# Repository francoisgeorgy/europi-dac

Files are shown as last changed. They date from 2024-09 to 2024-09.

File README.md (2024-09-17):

# A 4 channels DAC for the EuroPi

This is a custom PCB that add a four channels DAC to the [EuroPi](https://allensynthesis.co.uk/modules/europi.html).

The DAC is a [MCP4728](https://www.microchip.com/en-us/product/mcp4728) : 

* 12-Bit Resolution
* 4 Buffered Voltage Outputs
* Single-Supply Operation: 2.7V to 5.5V
* On-Board Non-Volatile Memory (EEPROM)
* Normal or Power-Down Mode
* Internal or External Voltage Reference Selection
* Rail-to-Rail Output
* Low Power Consumption
* ±0.2 LSB DNL (typical)
* Address bits: User Programmable toEEPROM
* Standard (100 kbps), Fast (400 kbps) and High Speed (3.4 Mbps) Modes

The voltage reference is a [LM4040](https://www.analog.com/en/products/lm4040.html), 3.0V. 

The DAC outputs are connected to the EuroPi 3, 4, 5 and 6 outputs as follows : 

| EuroPi output | DAC channel |
|---:|---:|
| 1 | |
| 2 | |
| 3 | D |
| 4 | B |
| 5 | C |
| 6 | A |

This specific order of the channels was chosen to facilitate the PCB routing. 

The EuroPi outputs 1 and 2 do not change and are still driven with a PWM output from the Pico.

#### Power supply : 

This custom PCB swaps the 10-pin Eurorack power connector for a 16-pin one and removes the onboard power regulator, 
opting to use the 5V directly from the Eurorack power supply instead.

## Schematic

Here is the schematic of this PCB : [dac-board-v2.1.pdf](hardware%2Fdac-board-v2.1%2Fplot%2Fdac-board-v2.1.pdf)

## Why build this custom PCB?

This PCB project was mainly a fun excuse to experiment and learn:

- [KiCad](https://www.kicad.org/) practice: a good opportunity to get better at PCB design.
- SMD assembly with [JLCPCB](https://jlcpcb.com/): tried out having the board made and assembled by an external provider.
- Eurorack power filtering: played around with filtering power right on the PCB.
- DAC vs PWM outputs: wanted to see if DAC outputs really outperform PWM for basic CV voltages.
- Just for fun: because DIY projects are always more fun!

## License

This custom PCB is licensed under the same terms and conditions as the original EuroPi. 

This module, and any documentation included in this repository, is entirely "free" software and hardware, 
under different licenses depending on the software, hardware, and documentation itself.

* Software: [Apache 2.0](software/LICENSE)
* Hardware: [CERN OHL-S v2](hardware/LICENSE)
* Documentation: [CC0 1.0](LICENSE)

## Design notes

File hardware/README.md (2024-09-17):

## PCB versions

### [dac-board](dac-board) 

Do not use this version. The J2 and J3 connectors (headers that link the front panel) are incorrectly oriented.

### [dac-board-v2](dac-board-v2) 

This version is OK and has been successfully used with a regular EuroPi front-panel. 

### [dac-board-v2.1](dac-board-v2.1) 

This minor release fixes the connectors placement in KiCad. This version has not been tested yet.

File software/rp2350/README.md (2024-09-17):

How to use the new Pi Pico 2 with EuroPi 
========================================

Pimoroni offers a Pico 2 board that is a drop-in replacement for the Pico :

[Pimoroni Pico Plus 2](https://shop.pimoroni.com/products/pimoroni-pico-plus-2?variant=42092668289107)

### To use this board : 

1. Download and install the Pimoroni firmware from https://github.com/pimoroni/pimoroni-pico-rp2350

Select the **pico_plus2_rp2350** MicroPython Flavour. 
The current release (september 16th) is [pico_plus2_rp2350-v0.0.7-pimoroni-micropython.uf2](https://github.com/pimoroni/pimoroni-pico-rp2350/releases/download/v0.0.7/pico_plus2_rp2350-v0.0.7-pimoroni-micropython.uf2). 

2. Install the ssd1306 package.
3. Install the EuroPi software from the source files. 
You must not install the `micropython-europi` package nor use a `europi-vX.Y.Z.uf2` file.
4. Adapt the EuroPi scripts to work with the Pico 2.

### Software changes for the Pico 2 : 

The only change that really needs to be made is related to the ADC. We need to use the ADC channel number instead
of the Pin number.

In `europi.py`, in the `__init__` method of the `AnalogReader` class, replace : 

    self.pin = ADC(Pin(pin))

with : 

    self.pin = ADC(pin)

In `europi.py`, in the main code (end of the file), replace : 

    ain = AnalogueInput(PIN_AIN)
    k1 = Knob(PIN_K1)
    k2 = Knob(PIN_K2)

with :

    ain = AnalogueInput(0)
    k1 = Knob(1)          
    k2 = Knob(2)

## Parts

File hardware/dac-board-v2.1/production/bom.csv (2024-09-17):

Designator | Footprint | Quantity | Value | LCSC Part #
C1 | 0805 | 1 | 10uF | C15850
C10, C3, C4, C5, C6, C7, C8, C9 | 0402 | 8 | 100nF
C20, C21, C22, C23, C24, C25 | 1206 | 6 | 22uF | C12891
D1 | D_SOD-323 | 1 | 1N5817WS | C727114
D2, D3, D4, D5 | D_SMA | 4 | STPS1L30 | C157388
FB1, FB2, FB3 | 0805 | 3 | FerriteBead | C216152
J2, J3 | PinSocket_2x04_P2.54mm_Vertical | 2 | Conn_02x04_Odd_Even
Q1 | SOT-23 | 1 | MBT2222A | C8512
R1, R2 | 0402 | 2 | 1K
R21, R22, R23 | 0402 | 3 | 22K
R24, R25, R26 | 0402 | 3 | 10K
R27, R28, R29, R30, R31, R32, R33, R34 | 0402 | 8 | 100K
R35, R36, R37, R38, R39, R40 | 0402 | 6 | 220K
TP1, TP2, TP3, TP4, TP5, TP6 | TestPoint_Pad_D1.5mm | 6 | TestPoint
U1 | SOT-23 | 1 | LM4040B30FTA | C460604
U2 | MSOP-10_3x3mm_P0.5mm | 1 | MCP4728 | C108207
U3, U4 | SOIC-14_3.9x8.7mm_P1.27mm | 2 | TL074 | C107644
U5 | SOIC-8_3.9x4.9mm_P1.27mm | 1 | MCP6002 | C7377

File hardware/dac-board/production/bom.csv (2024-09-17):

Designator | Footprint | Quantity | Value | LCSC Part #
C1 | 0805 | 1 | 10uF | C15850
C10, C11, C12, C13, C14, C3, C4, C5, C6, C7, C8, C9 | 0402 | 12 | 100nF
C2 | 0402 | 1 | 1uF | C52923
C20, C21, C22, C23, C24, C25 | 1206 | 6 | 22uF | C12891
D1 | D_SOD-323 | 1 | 1N5817WS | C727114
D2, D3, D4, D5 | D_SMA | 4 | STPS1L30 | C157388
FB1, FB2, FB3 | 0805 | 3 | FerriteBead | C216152
J5 | PinHeader_1x02_P2.54mm_Horizontal | 1 | Conn_01x02_Pin
Q1 | SOT-23 | 1 | MBT2222A | C8512
R1, R2, R3, R4, R5, R6 | 0402 | 6 | 1K
R21, R22, R23 | 0402 | 3 | 22K
R24, R25, R26 | 0402 | 3 | 10K
R27, R28, R29, R30, R31, R32, R33, R34 | 0402 | 8 | 100K
R35, R36, R37, R38, R39, R40 | 0402 | 6 | 220K
U1 | SOT-23 | 1 | LM4040LP-3 | C143326
U2 | MSOP-10_3x3mm_P0.5mm | 1 | MCP4728 | C108207
U3, U4 | SOIC-14_3.9x8.7mm_P1.27mm | 2 | TL074 | C107644
U5 | SOIC-8_3.9x4.9mm_P1.27mm | 1 | MCP6002 | C7377

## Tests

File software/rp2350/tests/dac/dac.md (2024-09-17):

Custom board with MCP4728 DAC
=============================

| Front-board jack | Pico PWM / DAC output |
|---|---|
| Output 1 | PWM1 |
| Output 2 | PWM2 |
| Output 3 | DAC D ch 3 |
| Output 4 | DAC B ch 1 |
| Output 5 | DAC C ch 2 |
| Output 6 | DAC A ch 0 |

Firmware 
--------

New classes : 

    OutputPWM
    OutputDAC

Changed class : 

    Output is parent of OutputPWM and OutputDAC

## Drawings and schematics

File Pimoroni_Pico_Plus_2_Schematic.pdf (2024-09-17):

## MCU2 RP2350B

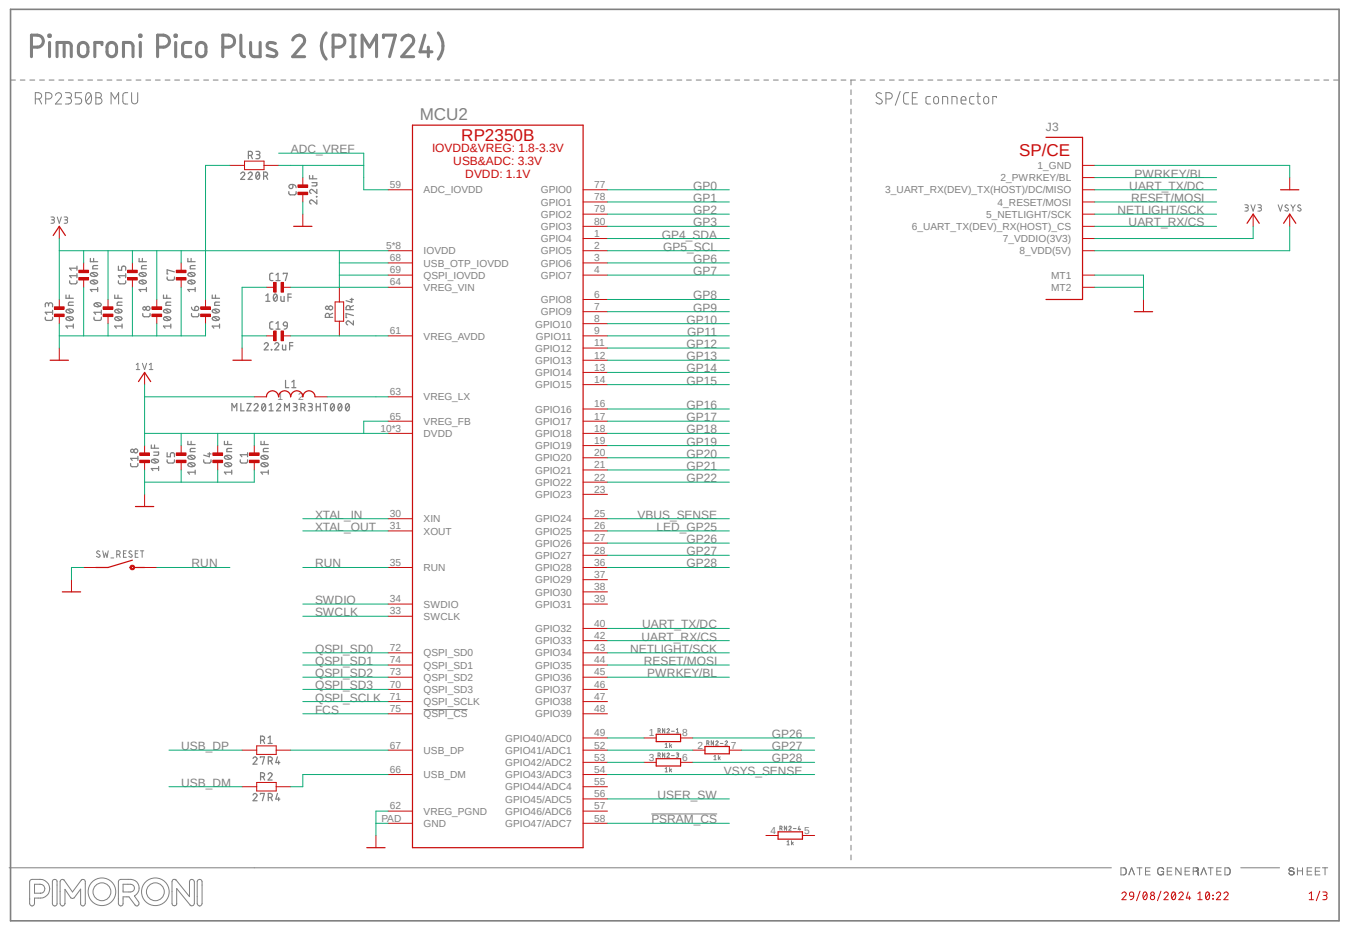
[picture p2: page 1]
IOVDD 5*8; GND PAD; QSPI_SD0 72 QSPI_SD1 74 QSPI_SD2 73 QSPI_SD3 70 QSPI_SCLK 71 QSPI_CS 75; VREG_AVDD 61; VREG_PGND 62; USB_DP 67; USB_DM 66; SWCLK 33; SWDIO 34; RUN 35; XOUT 31; ADC_IOVDD 59; GPIO0; GPIO1; GPIO2; GPIO3; GPIO4; GPIO5; GPIO6; GPIO7; GPIO8; GPIO9; GPIO10; GPIO11; GPIO12; GPIO13; GPIO14; GPIO15; GPIO16; GPIO17; GPIO18; GPIO19; GPIO20; GPIO21; GPIO22; GPIO23; GPIO24; GPIO25; VREG_FB 65; VREG_LX 63; GPIO26; GPIO27; GPIO28; GPIO29; GPIO30; GPIO31; GPIO32; GPIO33; GPIO34; GPIO35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

3_UART_RX(DEV)_TX(HOST)/DC/MISO

USB_OTP_IOVDD 68 | GP6
QSPI_IOVDD 69 | GP7
VREG_VIN 64 | GP8

DVDD 10*3 | GP18

XTAL_IN | XIN 30 | GP19

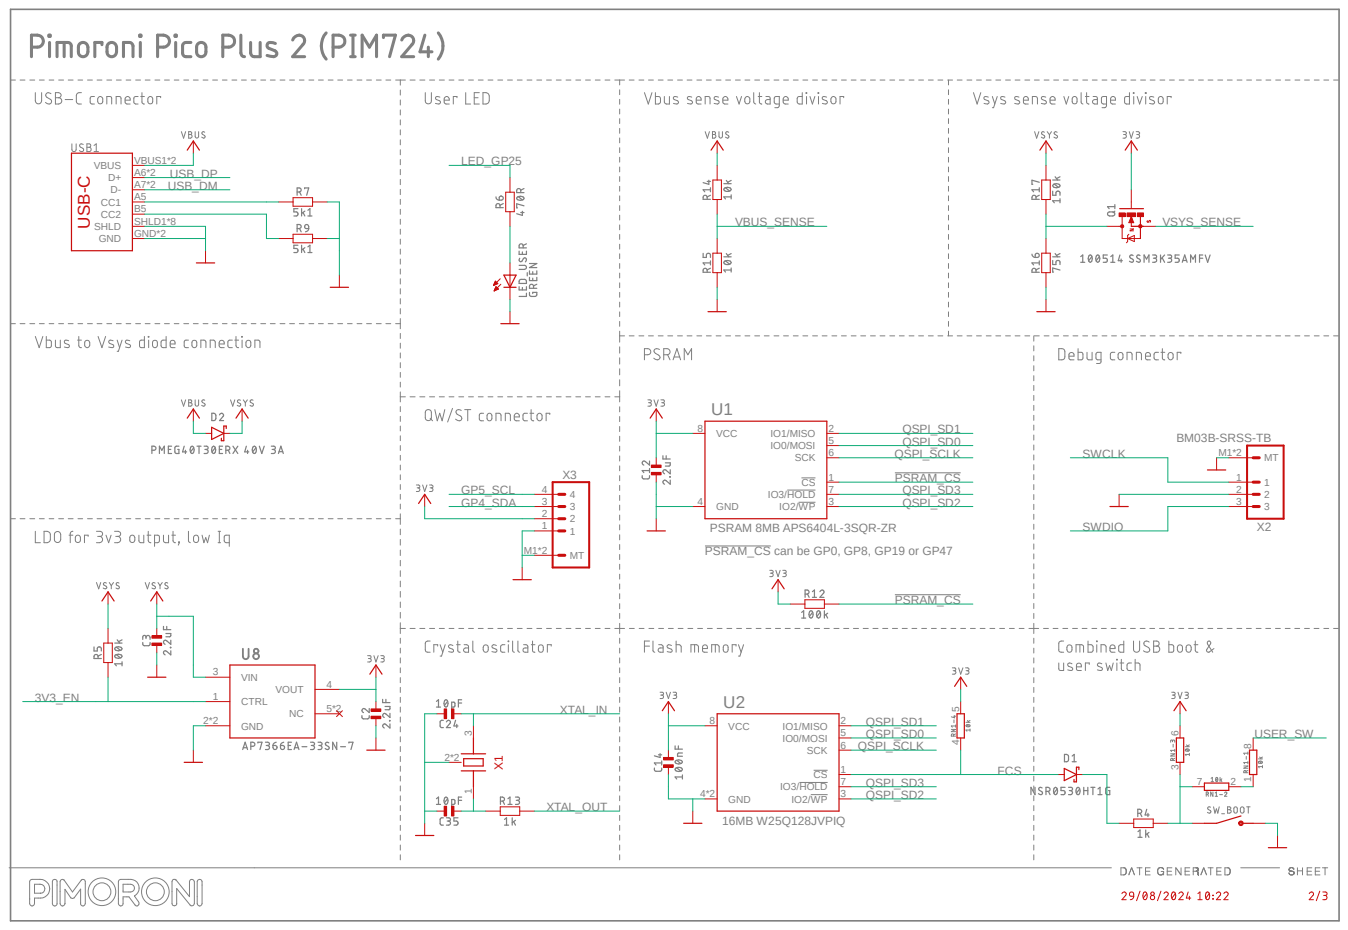
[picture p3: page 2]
16MB W25Q128JVPIQ; BM03B-SRSS-TB; GND; GND*2; VBUS; VBUS1*2; SHLD; SHLD1*8; 2 ³ ⁶ ⁴ ⁵ VCC 8; IO1/MISO; IO0/MOSI; GND 4*2; SCK; IO3/HOLD; VCC 8; VIN 3; GND 2*2; CTRL 1; VOUT; USB_DP USB_DM; QSPI_SD1; QSPI_SD2; QSPI_SD3; QSPI_SCLK; FCS; XTAL_IN; XTAL_OUT; QSPI_SD0; USER_SW; GP5_SCL; LED_GP25; GP4_SDA; PSRAM_CS; VBUS_SENSE; VSYS_SENSE; SWCLK; SWDIO; 3V3_EN USB⁻C

GND 4
PSRAM 8MB APS6404L-3SQR-ZR
PSRAM_CS can be GP0, GP8, GP19 or GP47

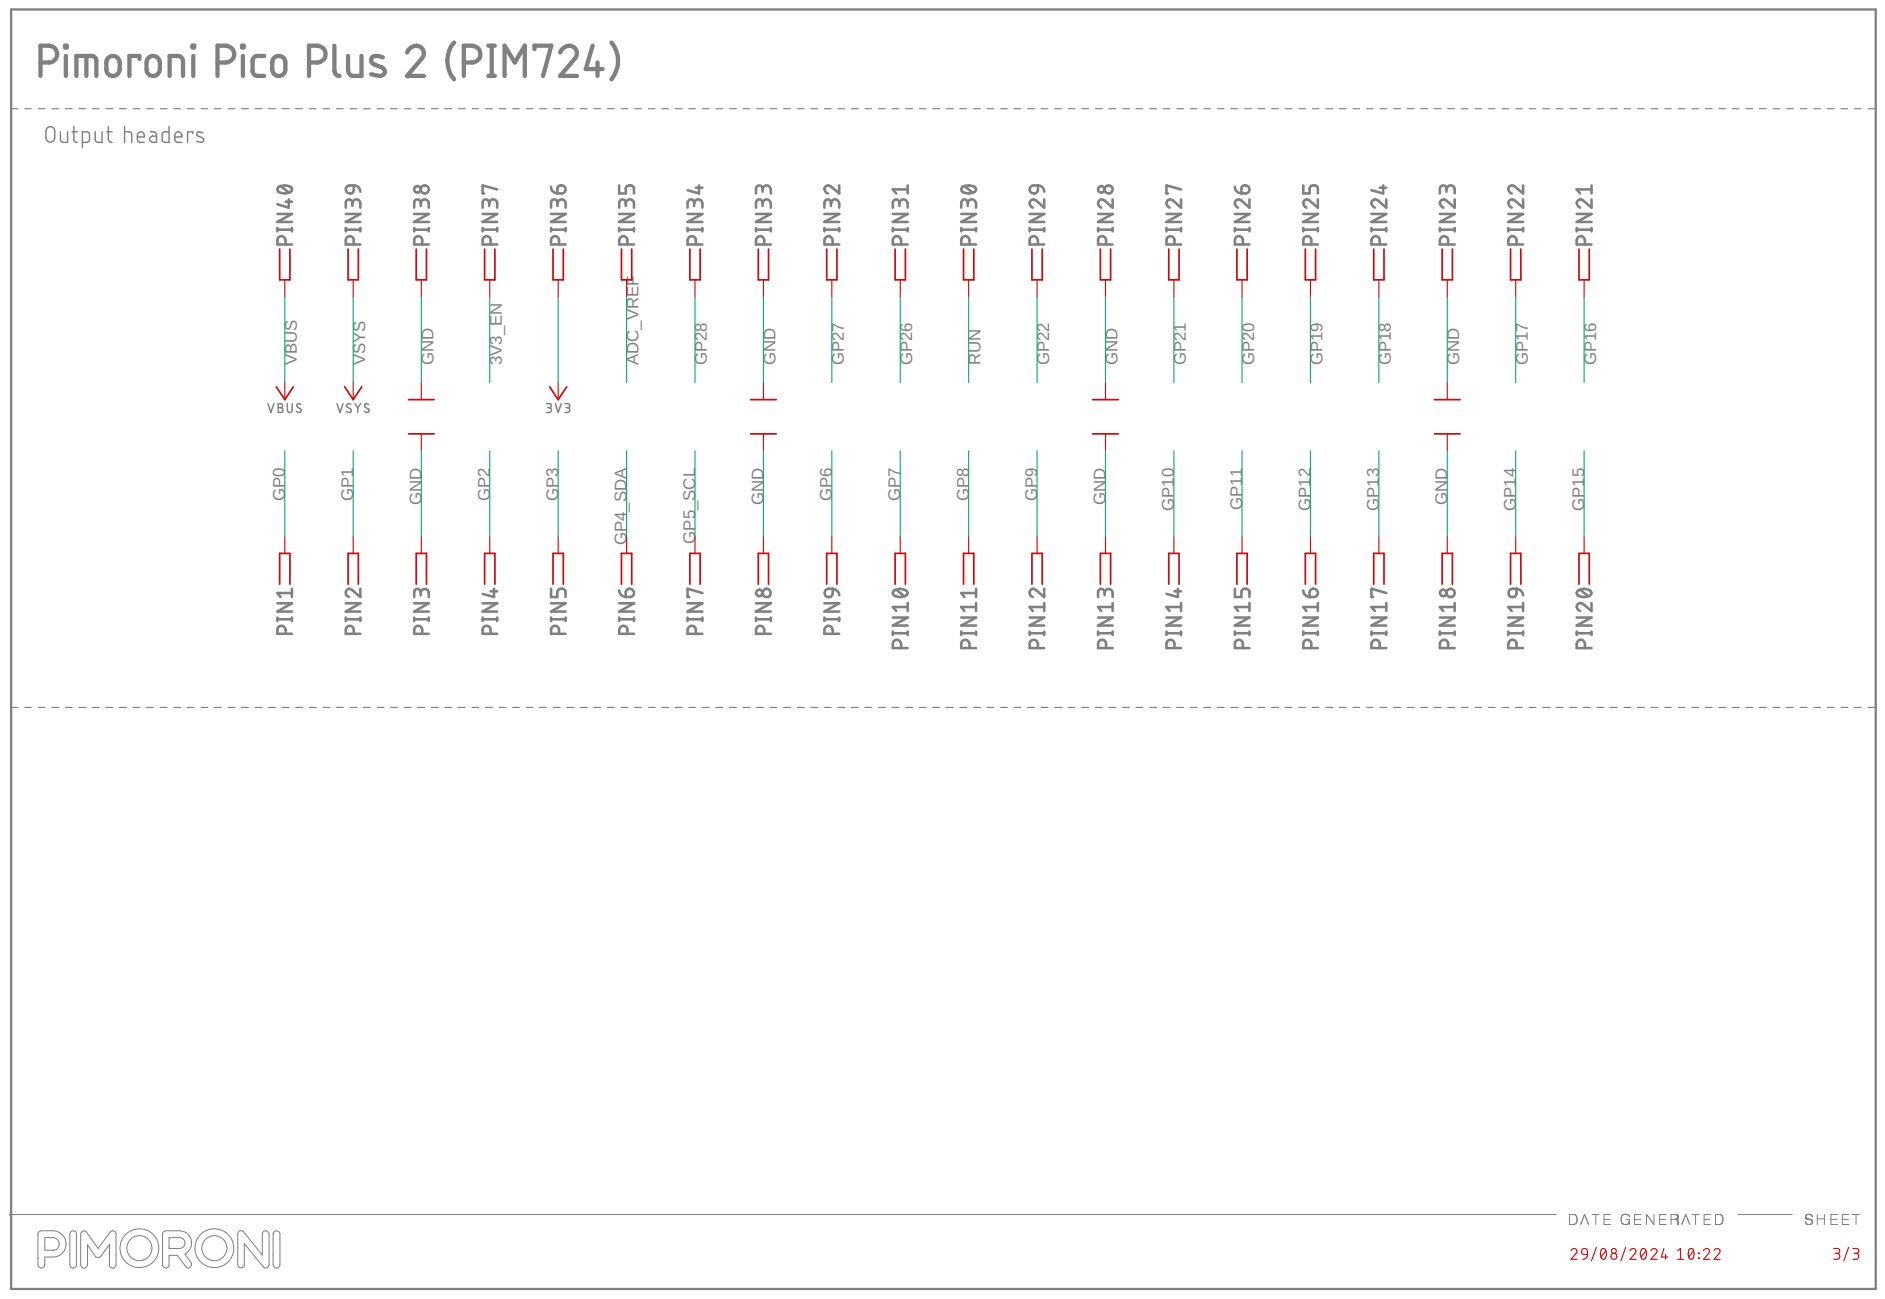
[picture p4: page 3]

GND GND GND GND GND GND GND GND GP0 GP1 GP2 GP3 GP4_SDA GP5_SCL GP6 GP7 GP8 GP9 GP10 GP11 GP12 GP13 GP14 GP15 VBUS VSYS 3V3_EN ADC_VREF GP28 GP27 GP26 RUN GP22 GP21 GP20 GP19 GP18 GP17 GP16

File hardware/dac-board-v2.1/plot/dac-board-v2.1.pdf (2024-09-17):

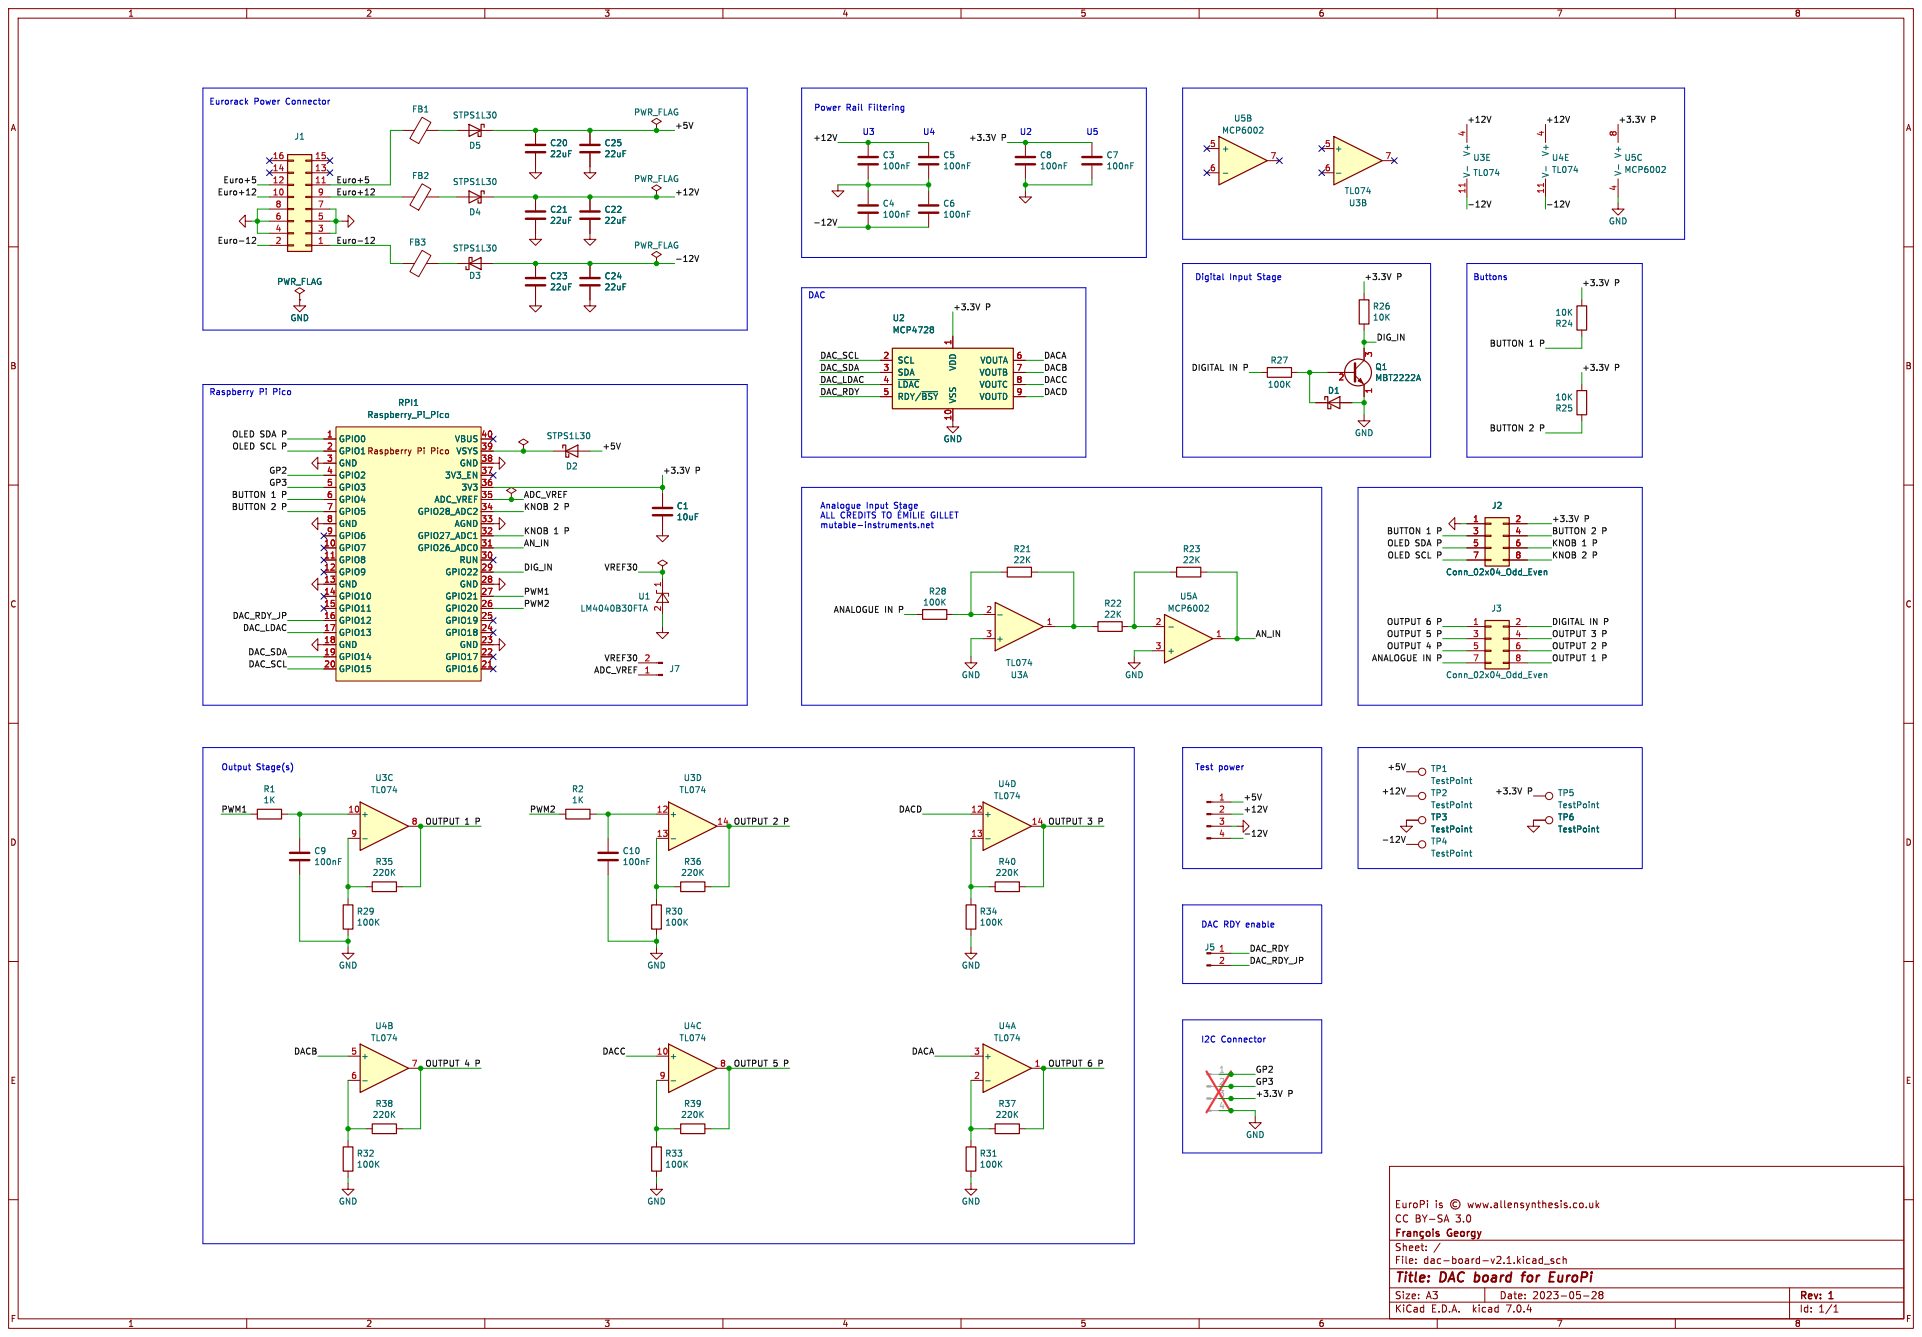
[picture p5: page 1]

1 VSS 10 SCL 2 SDA 3 ~{LDAC} 4 RDY/~{BSY} 5 VOUTA 6 VOUTB 7 VOUTC 8 VOUTD 9 U2 MCP4728 FB2 PWR_FLAG

Power Rail Filtering DAC

1 VSS 10 SCL 2 SDA 3 ~{LDAC} 4 RDY/~{BSY} 5 VOUTA 6 VOUTB 7 VOUTC 8 VOUTD 9 GND GND

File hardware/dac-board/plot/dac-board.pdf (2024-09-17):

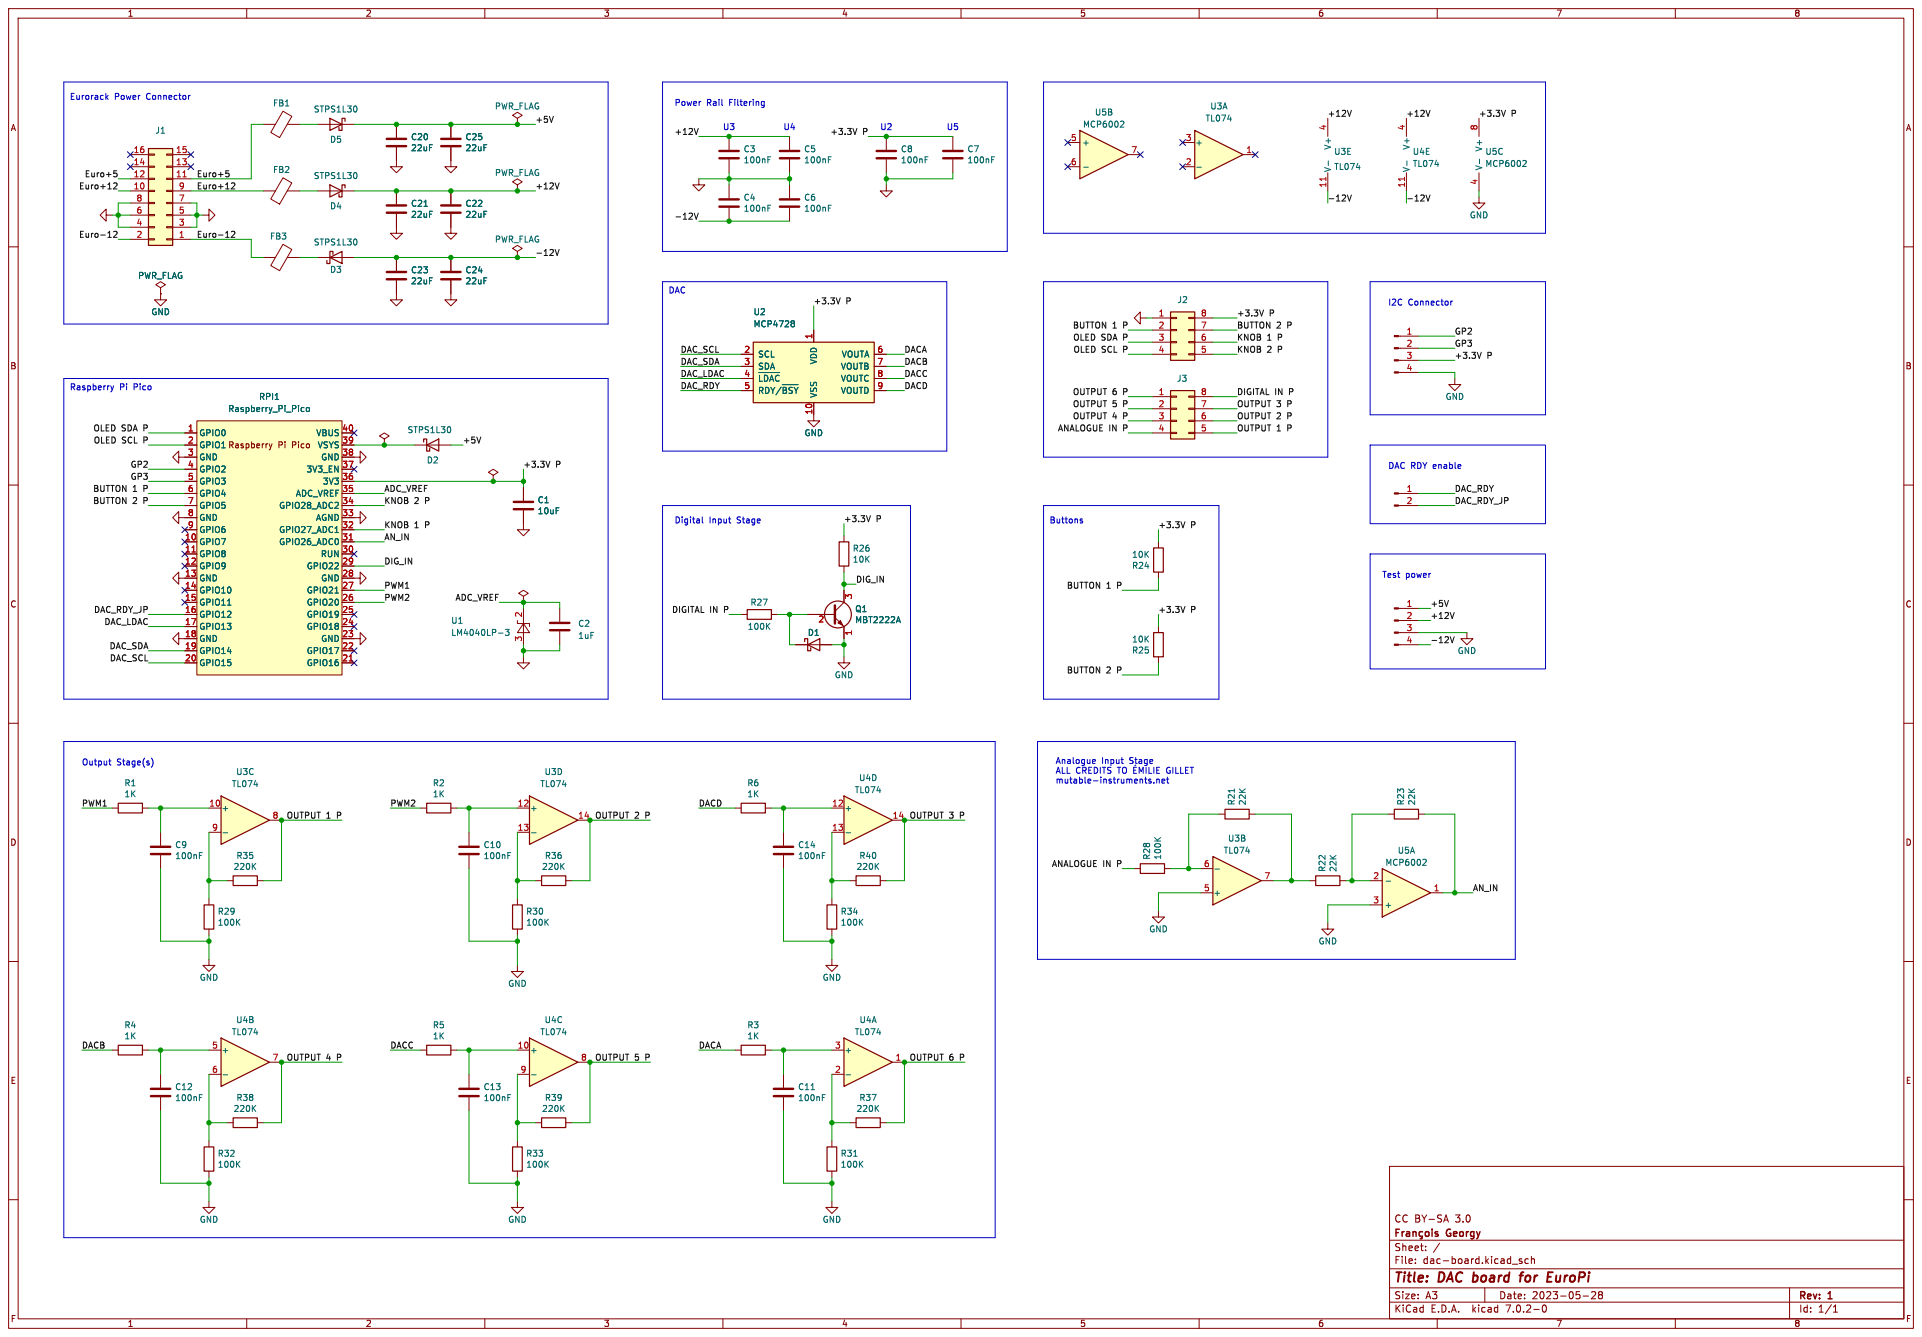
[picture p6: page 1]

U3 Power Rail Filtering Eurorack Power Connector

1 VSS 10 SCL 2 SDA 3 ~{LDAC} 4 RDY/~{BSY} 5 VOUTA 6 VOUTB 7 VOUTC 8 VOUTD 9 U2 MCP4728 +
ADC_VREF PWM2 KNOB 2 P

BUTTON 1 P OUTPUT 5 P OLED SCL P OLED SDA P

BUTTON 2 P
KNOB 1 P
KNOB 2 P DIGITAL IN P OUTPUT 3 P

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

DAC RDY enable Digital Input Stage

Analogue Input Stage ALL CREDITS TO þÿÉMILIE GLLET mutable-instruments.net

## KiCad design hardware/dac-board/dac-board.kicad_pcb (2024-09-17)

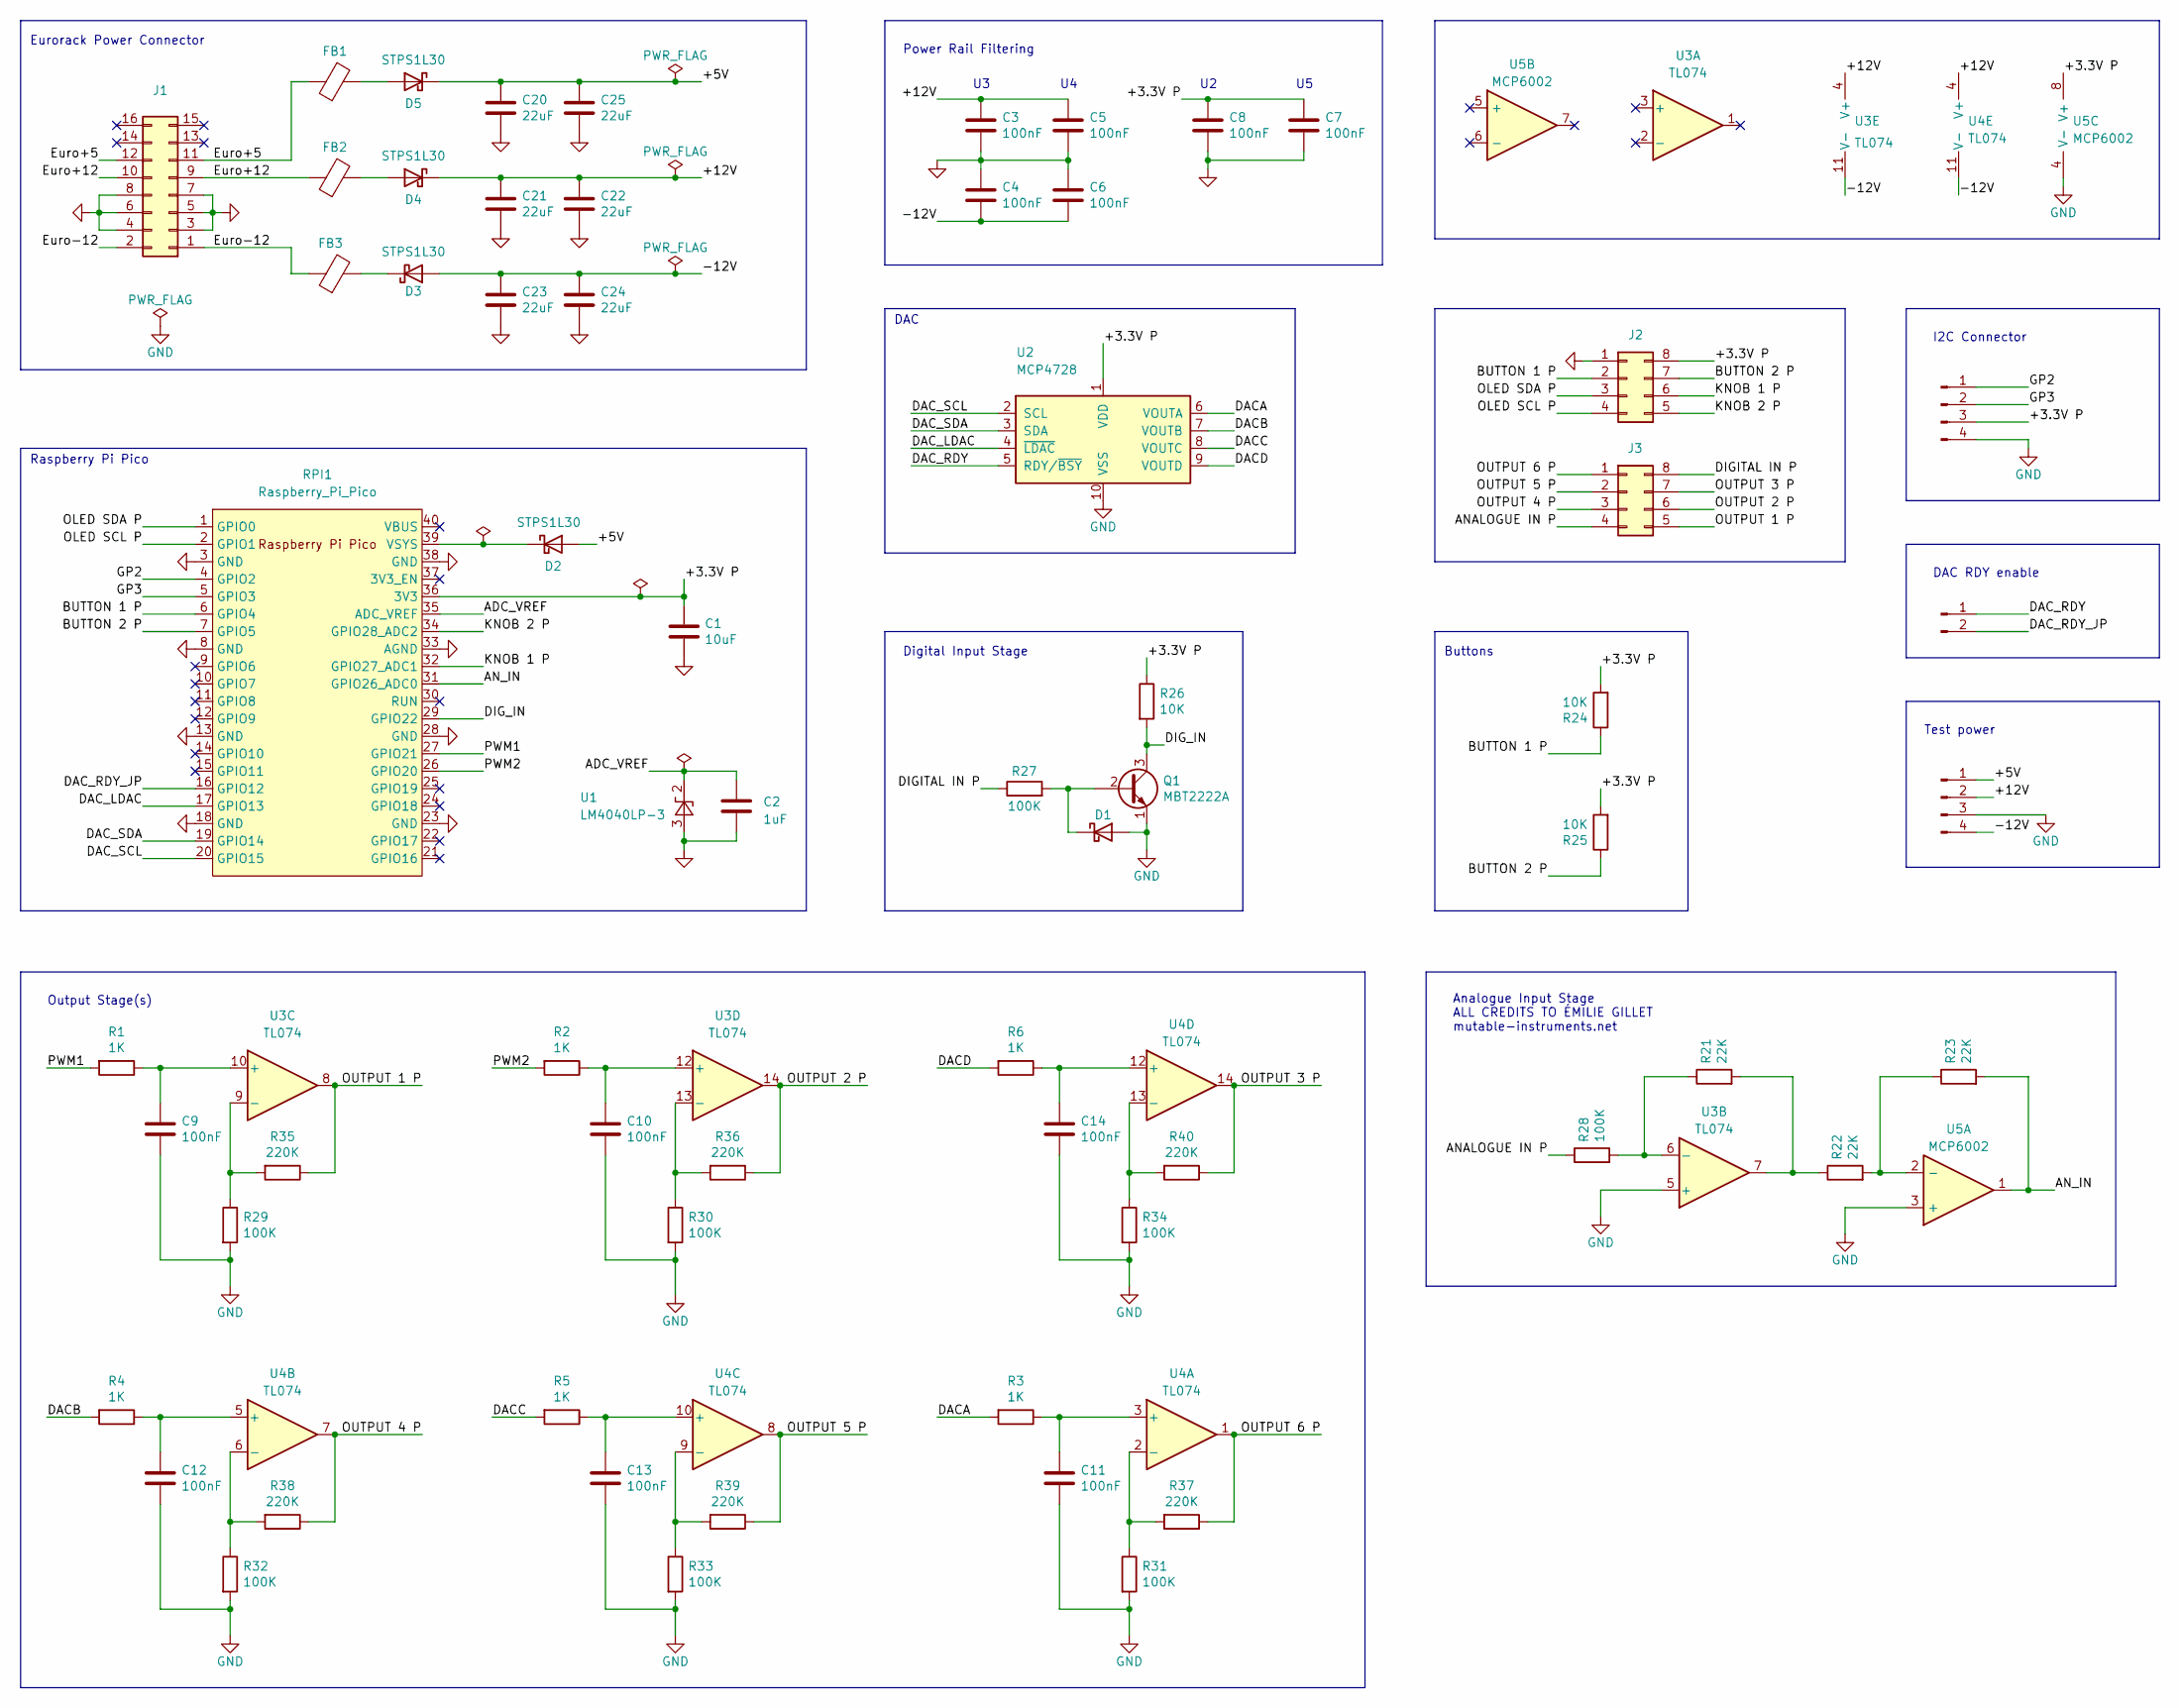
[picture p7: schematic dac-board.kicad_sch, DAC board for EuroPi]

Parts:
C1: 10uF; C_0805_2012Metric; JLCPCB Part # C15850
C2: 1uF; C_0402_1005Metric; JLCPCB Part # C52923
C3, C4, C5, C6, C7, C8, C9, C10, C11, C12, C13, C14: 100nF; C_0402_1005Metric
C20, C21, C22, C23, C24, C25: 22uF; C_1206_3216Metric; JLCPCB Part # C12891
D1: 1N5817WS; D_SOD-323; JLCPCB Part # C727114
D2, D3, D4, D5: STPS1L30; D_SMA; JLCPCB Part # C157388
FB1, FB2, FB3: FerriteBead; L_0805_2012Metric; JLCPCB Part # C216152
J1: Conn_02x08_Odd_Even; IDC-Header_2x08_P2.54mm_Vertical
J2, J3: Conn_02x04_Counter_Clockwise; PinHeader_2x04_P2.54mm_Vertical
J4, J6: Conn_01x04_Male; PinHeader_1x04_P2.54mm_Vertical
J5: Conn_01x02_Pin; PinHeader_1x02_P2.54mm_Horizontal
Q1: MBT2222A; SOT-23; JLCPCB Part # C8512
R1, R2, R3, R4, R5, R6: 1K; R_0402_1005Metric
R21, R22, R23: 22K; R_0402_1005Metric
R24, R25, R26: 10K; R_0402_1005Metric
R27, R28, R29, R30, R31, R32, R33, R34: 100K; R_0402_1005Metric
R35, R36, R37, R38, R39, R40: 220K; R_0402_1005Metric
RPI1: Raspberry_Pi_Pico; Raspberry Pi Pico
U1: LM4040LP-3; SOT-23; JLCPCB Part # C143326
U2: MCP4728; MSOP-10_3x3mm_P0.5mm; JLCPCB Part # C108207
U3, U4: TL074; SOIC-14_3.9x8.7mm_P1.27mm; JLCPCB Part # C107644
U5: MCP6002; SOIC-8_3.9x4.9mm_P1.27mm; JLCPCB Part # C7377

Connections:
/+3.3V P: C1.1, C7.1, C8.1, J2.8, J4.3, R24.2, R25.2, R26.1, RPI1.36 (3V3), U2.1 (VDD), U5.8 (V+)
/+5V: C20.1, C25.1, D2.2 (A), D5.1 (K), J6.1
/+12V: C3.1, C5.1, C21.1, C22.1, D4.1 (K), J6.2, U3.4 (V+), U4.4 (V+)
/-12V: C4.2, C6.2, C23.1, C24.1, D3.2 (A), J6.4, U3.11 (V-), U4.11 (V-)
/ADC_VREF: C2.1, RPI1.35 (ADC_VREF), U1.2 (K)
/ANALOGUE IN P: J3.4, R28.1
/AN_IN: R23.2, RPI1.31 (GPIO26_ADC0), U5.1
/BUTTON 1 P: J2.2, R24.1, RPI1.6 (GPIO4)
/BUTTON 2 P: J2.7, R25.1, RPI1.7 (GPIO5)
/DACA: R3.2, U2.6 (VOUTA)
/DACB: R4.2, U2.7 (VOUTB)
/DACC: R5.2, U2.8 (VOUTC)
/DACD: R6.2, U2.9 (VOUTD)
/DAC_LDAC: RPI1.17 (GPIO13), U2.4 (~LDAC)
/DAC_RDY: J5.1, U2.5 (RDY/~BSY)
/DAC_RDY_JP: J5.2, RPI1.16 (GPIO12)
/DAC_SCL: RPI1.20 (GPIO15), U2.2 (SCL)
/DAC_SDA: RPI1.19 (GPIO14), U2.3 (SDA)
/DIGITAL IN P: J3.8, R27.1
/DIG_IN: Q1.3 (C), R26.2, RPI1.29 (GPIO22)
/Euro+5: FB1.1, J1.11, J1.12
/Euro+12: FB2.1, J1.9, J1.10
/Euro-12: FB3.1, J1.1, J1.2
/GP2: J4.1, RPI1.4 (GPIO2)
/GP3: J4.2, RPI1.5 (GPIO3)
/KNOB 1 P: J2.6, RPI1.32 (GPIO27_ADC1)
/KNOB 2 P: J2.5, RPI1.34 (GPIO28_ADC2)
/OLED SCL P: J2.4, RPI1.2 (GPIO1)
/OLED SDA P: J2.3, RPI1.1 (GPIO0)
/OUTPUT 1 P: J3.5, R35.1, U3.8
/OUTPUT 2 P: J3.6, R36.1, U3.14
/OUTPUT 3 P: J3.7, R40.1, U4.14
/OUTPUT 4 P: J3.3, R38.1, U4.7
/OUTPUT 5 P: J3.2, R39.1, U4.8
/OUTPUT 6 P: J3.1, R37.1, U4.1
/PWM1: R1.2, RPI1.27 (GPIO21)
/PWM2: R2.2, RPI1.26 (GPIO20)
GND: C1.2, C2.2, C3.2, C4.1, C5.2, C6.1, C7.2, C8.2, C9.2, C10.2, C11.2, C12.2, C13.2, C14.2, C20.2, C21.2, C22.2, C23.2, C24.2, C25.2, D1.2 (A), J1.3, J1.4, J1.5, J1.6, J1.7, J1.8, J2.1, J4.4, J6.3, Q1.1 (E), R29.2, R30.2, R31.2, R32.2, R33.2, R34.2, RPI1.3 (GND), RPI1.8 (GND), RPI1.13 (GND), RPI1.18 (GND), RPI1.23 (GND), RPI1.28 (GND), RPI1.33 (AGND), RPI1.38 (GND), U1.3 (A), U2.10 (VSS), U3.5 (+), U5.3 (+), U5.4 (V-)
unnamed: D1.1 (K), Q1.2 (B), R27.2
unnamed: D2.1 (K), RPI1.39 (VSYS)
unnamed: D3.1 (K), FB3.2
unnamed: D4.2 (A), FB2.2
unnamed: D5.2 (A), FB1.2
unnamed: R21.2, R22.1, U3.7
unnamed: R21.1, R28.2, U3.6 (-)
unnamed: C9.1, R1.1, U3.10 (+)
unnamed: R29.1, R35.2, U3.9 (-)
unnamed: C10.1, R2.1, U3.12 (+)
unnamed: R30.1, R36.2, U3.13 (-)
unnamed: C11.1, R3.1, U4.3 (+)
unnamed: R31.1, R37.2, U4.2 (-)
unnamed: C12.1, R4.1, U4.5 (+)
unnamed: R32.1, R38.2, U4.6 (-)
unnamed: C13.1, R5.1, U4.10 (+)
unnamed: R33.1, R39.2, U4.9 (-)
unnamed: C14.1, R6.1, U4.12 (+)
unnamed: R34.1, R40.2, U4.13 (-)
unnamed: R22.2, R23.1, U5.2 (-)

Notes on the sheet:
Buttons
Analogue Input Stage ALL CREDITS TO ÉMILIE GILLET mutable-instruments.net
Power Rail Filtering
Eurorack Power Connector
I2C Connector
Digital Input Stage
DAC
Raspberry Pi Pico
Output Stage(s)
Test power
DAC RDY enable

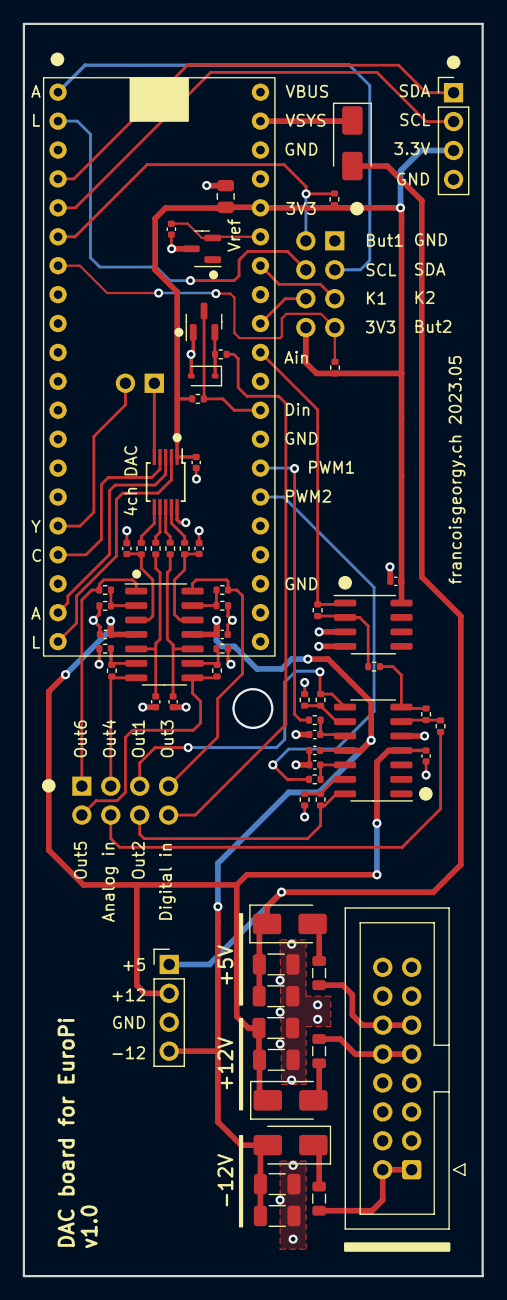
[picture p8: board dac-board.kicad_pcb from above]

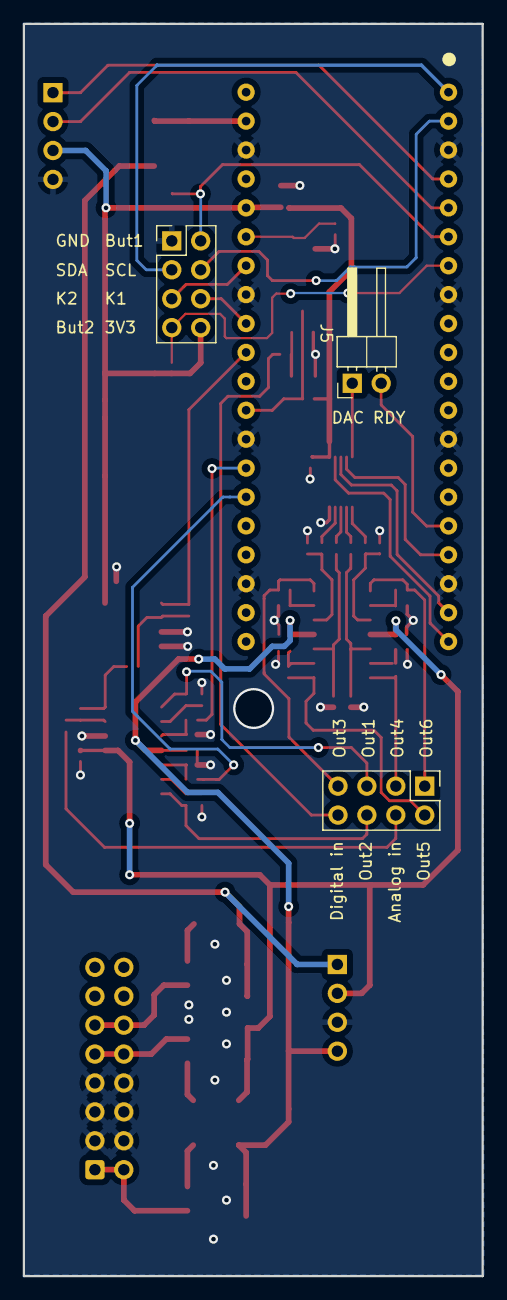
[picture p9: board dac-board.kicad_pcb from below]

Board: 2 copper layers, 40.3 x 110.0 mm, 67 parts (3 on the bottom side), 58 nets.

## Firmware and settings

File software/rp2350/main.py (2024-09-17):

"""See menu.md for details."""
# from bootloader import BootloaderMenu
from calibrate_input import CalibrateInput
from europi import bootsplash, usb_connected, oled
# from calibrate import Calibrate

# This is a fix for a USB connection issue documented in GitHub issue #179, and its removal condition is set out in
# GitHub issue #184
if usb_connected.value() == 0:
    from time import sleep
    sleep(0.5)

# Reset the module state and display bootsplash screen.
bootsplash()

EUROPI_SCRIPT_CLASSES = [
    CalibrateInput
]


if __name__ == "__main__":
    oled.contrast(0)  # dim the display
    # BootloaderMenu(EUROPI_SCRIPT_CLASSES).main()
    CalibrateInput().main()

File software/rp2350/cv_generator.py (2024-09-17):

"""
DAC CV Generator
author: François Georgy (https://github.com/francoisgeorgy)
date: 2023-06-30
labels: dac, cv, tuner

Output to CV3..6 a voltage defined by Knob1 and Knob2.

Knob-1 sets the integer part from 0 to 9.
Knob-2 sets the fractional part from 0 to 99.

This allows to output a voltage in the range 0.00 to 9.99V.
"""
from time import sleep

from europi import cv1, cv2, cv3, cv4, cv5, cv6, k1, k2, oled, ain
from europi_script import EuroPiScript


class CvGenerator(EuroPiScript):
    @classmethod
    def display_name(cls):
        return "DAC CV Generator"

    def __init__(self):
        super().__init__()

    def main(self):
        padding = 5  # pixels left and right
        while True:
            v = k1.read_position(10) + k2.read_position(100) / 100.0
            v1 = cv1.voltage(v)
            v2 = cv2.voltage(v)
            v3 = cv3.voltage(v)
            v4 = cv4.voltage(v)
            v5 = cv5.voltage(v)
            v6 = cv6.voltage(v)
            vin = ain.read_voltage()
            oled.fill(0)
            oled.text(f"{v:2.2f}V v3={v3}", 5, 4)
            oled.text(f"Vin={vin}", 5, 15)
            oled.show()
            sleep(0.1)


if __name__ == "__main__":
    oled.contrast(0)  # dim the display
    CvGenerator().main()

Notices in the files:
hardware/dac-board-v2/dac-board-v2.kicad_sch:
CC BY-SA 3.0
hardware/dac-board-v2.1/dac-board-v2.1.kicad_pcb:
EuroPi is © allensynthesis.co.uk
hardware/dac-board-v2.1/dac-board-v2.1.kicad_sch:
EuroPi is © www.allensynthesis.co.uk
